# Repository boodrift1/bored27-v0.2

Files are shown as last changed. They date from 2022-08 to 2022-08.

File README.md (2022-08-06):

# bored27-v0.2
*WARNING: This PCB has not been tested and there is currently no firmware available for it.

bored27 - 27 key PCB inspired by flurples' cardboard keyboard: https://www.youtube.com/watch?v=sVInBOLSqoM <br />
designed for use with plate provided in original video description

changes from v0.1: <br />
moved diodes to front (inspired by mode designs' pcbs) <br />
changed from atmega32u4 to atmega32u2 (less components, simpler, cheaper)

designed w/ kicad

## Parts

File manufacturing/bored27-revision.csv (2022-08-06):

Id | Designator | Package | Quantity | Designation | Supplier and ref
1 | R3,R4 | R_0805_2012Metric_Pad1.20x1.40mm_HandSolder | 2 | 22
2 | C4,C5 | C_0805_2012Metric_Pad1.18x1.45mm_HandSolder | 2 | 0.1uF
3 | D13,D15,D23,D1,D9,D26,D5,D24,D2,D16,D8,D25,D21,D22,D18,D12,D10,D27,D7,D20,D6,D14,D19,D17,D11,D3,D4 | D_SOD-123 | 27 | D
4 | R6,R5 | R_0805_2012Metric_Pad1.20x1.40mm_HandSolder | 2 | 10k
5 | FB1 | L_0805_2012Metric_Pad1.15x1.40mm_HandSolder | 1 | 60@100MHz
6 | C6 | C_0805_2012Metric_Pad1.18x1.45mm_HandSolder | 1 | 10uF
7 | U2 | SOT143B | 1 | PRTR5V0U2X
8 | C1,C2 | C_0805_2012Metric_Pad1.18x1.45mm_HandSolder | 2 | 22pF
9 | SW1 | SW_SPST_SKQG_WithStem | 1 | SW_Push
10 | F1 | Fuse_1206_3216Metric_Pad1.42x1.75mm_HandSolder | 1 | 500mA
11 | X1 | Crystal_SMD_3225-4Pin_3.2x2.5mm_HandSoldering | 1 | 16MHz
12 | R1,R2 | R_0805_2012Metric_Pad1.20x1.40mm_HandSolder | 2 | 5.1k
13 | C3 | C_0805_2012Metric_Pad1.18x1.45mm_HandSolder | 1 | 1uF
14 | J1 | USB_C_Receptacle_HRO_TYPE-C-31-M-12 | 1 | USB_C_Receptacle_USB2.0
15 | U1 | TQFP-32_7x7mm_P0.8mm | 1 | ATmega32U2-A
16 | K5 | SW_MX_HS_1u | 1 | T
17 | K14 | SW_MX_HS_1u | 1 | F
18 | K11 | SW_MX_HS_1u | 1 | A
19 | K25 | SW_MX_HS_1u | 1 | N
20 | K16 | SW_MX_HS_1u | 1 | H
21 | K10 | SW_MX_HS_1u | 1 | P
22 | K8 | SW_MX_HS_1u | 1 | I
23 | K9 | SW_MX_HS_1u | 1 | O
24 | J2 | Reset_Pretty-Mask | 1 | AVR-ISP-6
25 | K13 | SW_MX_HS_1u | 1 | D
26 | K24 | SW_MX_HS_1u | 1 | B
27 | K7 | SW_MX_HS_1u | 1 | U
28 | K27 | SW_MX_HS_1u | 1 | SPACE
29 | K19 | SW_MX_HS_1u | 1 | L
30 | K22 | SW_MX_HS_1u | 1 | C
31 | K23 | SW_MX_HS_1u | 1 | V
32 | K21 | SW_MX_HS_1u | 1 | X
33 | K4 | SW_MX_HS_1u | 1 | R
34 | K18 | SW_MX_HS_1u | 1 | K
35 | K3 | SW_MX_HS_1u | 1 | E
36 | K15 | SW_MX_HS_1u | 1 | G
37 | K2 | SW_MX_HS_1u | 1 | W
38 | K20 | SW_MX_HS_1u | 1 | Z
39 | K17 | SW_MX_HS_1u | 1 | J
40 | K26 | SW_MX_HS_1u | 1 | M
41 | K1 | SW_MX_HS_1u | 1 | Q
42 | K12 | SW_MX_HS_1u | 1 | S
43 | K6 | SW_MX_HS_1u | 1 | Y

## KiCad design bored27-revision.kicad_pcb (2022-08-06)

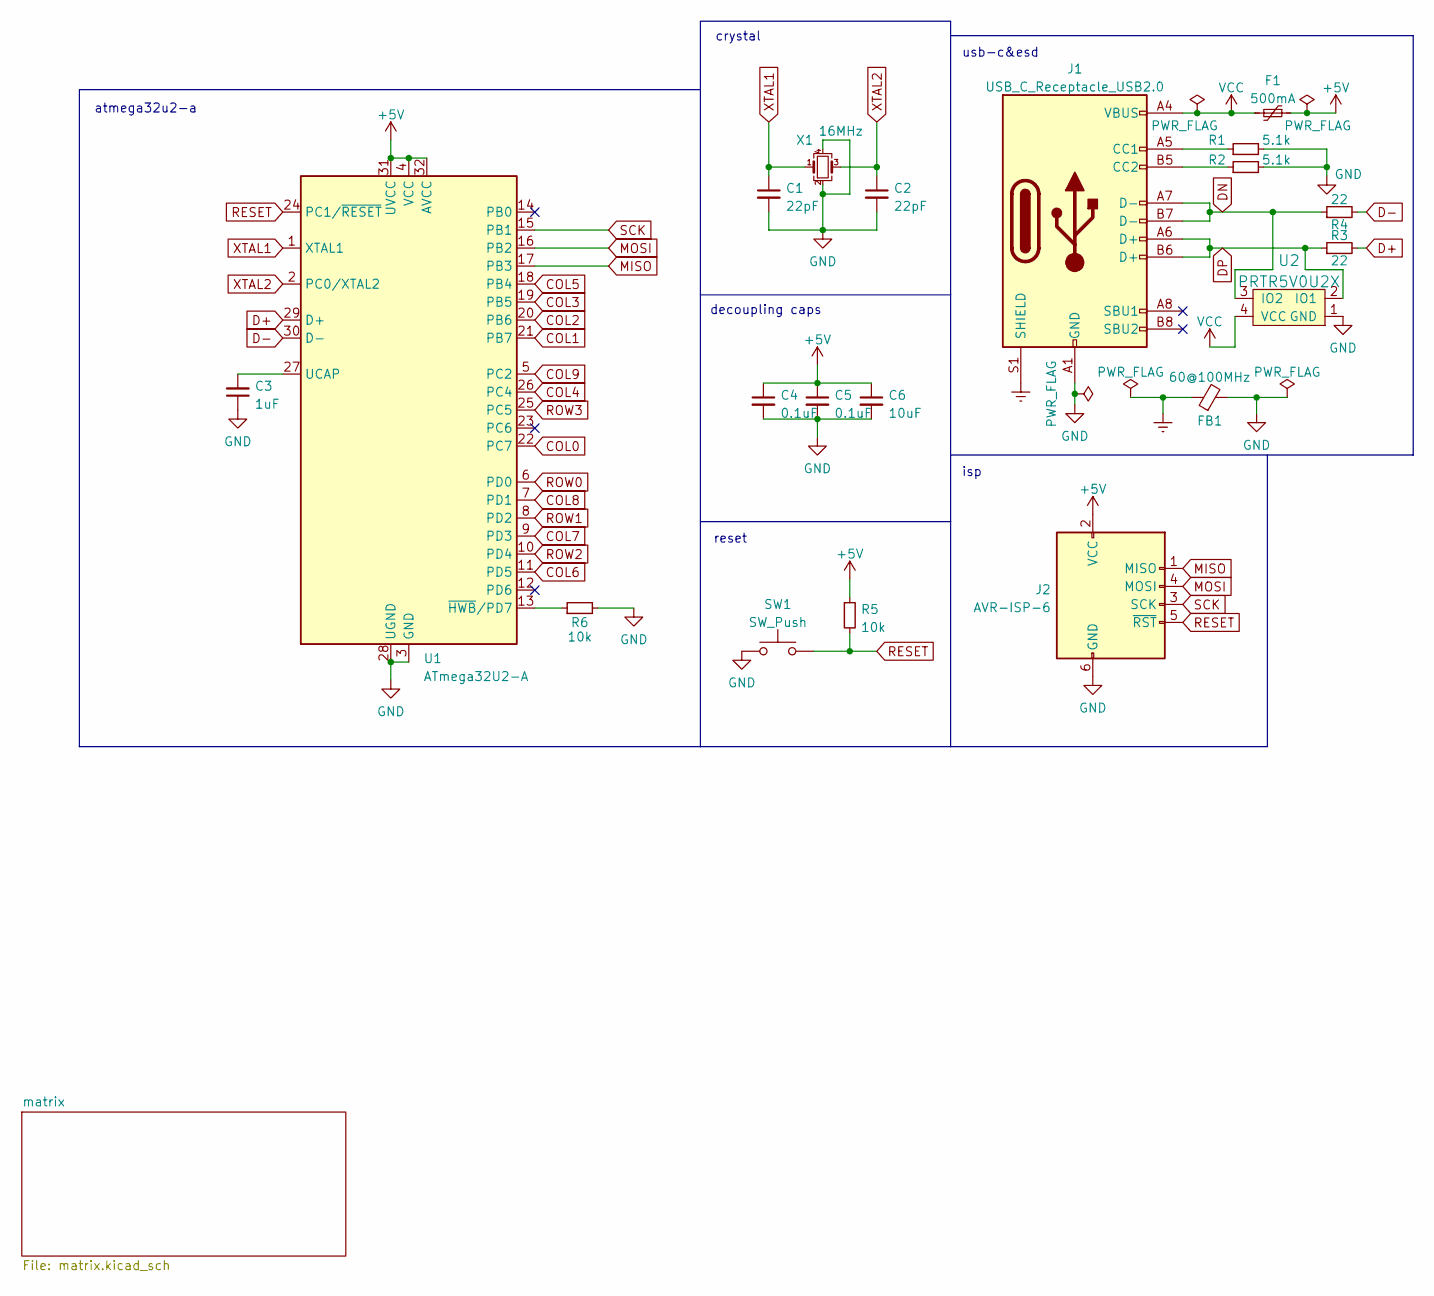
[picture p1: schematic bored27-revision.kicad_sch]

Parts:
C1, C2: 22pF; C_0805_2012Metric_Pad1.18x1.45mm_HandSolder
C3: 1uF; C_0805_2012Metric_Pad1.18x1.45mm_HandSolder
C4, C5: 0.1uF; C_0805_2012Metric_Pad1.18x1.45mm_HandSolder
C6: 10uF; C_0805_2012Metric_Pad1.18x1.45mm_HandSolder
F1: 500mA; Fuse_1206_3216Metric_Pad1.42x1.75mm_HandSolder
FB1: 60@100MHz; L_0805_2012Metric_Pad1.15x1.40mm_HandSolder
J1: USB_C_Receptacle_USB2.0; USB_C_Receptacle_HRO_TYPE-C-31-M-12
J2: AVR-ISP-6; Reset_Pretty-Mask
R1, R2: 5.1k; R_0805_2012Metric_Pad1.20x1.40mm_HandSolder
R3, R4: 22; R_0805_2012Metric_Pad1.20x1.40mm_HandSolder
R5, R6: 10k; R_0805_2012Metric_Pad1.20x1.40mm_HandSolder
SW1: SW_Push; SW_SPST_SKQG_WithStem
U1: ATmega32U2-A; TQFP-32_7x7mm_P0.8mm
U2: PRTR5V0U2X; SOT143B
X1: 16MHz; Crystal_SMD_3225-4Pin_3.2x2.5mm_HandSoldering

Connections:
+5V: C4.1, C5.1, C6.1, F1.1, J2.2 (VCC), R5.1, U1.4 (VCC), U1.31 (UVCC), U1.32 (AVCC)
COL0: U1.22 (PC7); also elsewhere on the board
COL1: U1.21 (PB7); also elsewhere on the board
COL2: U1.20 (PB6); also elsewhere on the board
COL3: U1.19 (PB5); also elsewhere on the board
COL4: U1.26 (PC4); also elsewhere on the board
COL5: U1.18 (PB4); also elsewhere on the board
COL6: U1.11 (PD5); also elsewhere on the board
COL7: U1.9 (PD3); also elsewhere on the board
COL8: U1.7 (PD1); also elsewhere on the board
COL9: U1.5 (PC2); also elsewhere on the board
D+: R3.2, U1.29 (D+)
D-: R4.2, U1.30 (D-)
DN: J1.A7 (D-), J1.B7 (D-), R4.1, U2.3 (IO2)
DP: J1.A6 (D+), J1.B6 (D+), R3.1, U2.2 (IO1)
Earth: FB1.1, J1.S1 (SHIELD)
GND: C1.2, C2.2, C3.1, C4.2, C5.2, C6.2, FB1.2, J1.A1 (GND), J1.A12 (GND), J1.B1 (GND), J1.B12 (GND), J2.6 (GND), R1.2, R2.2, R6.2, SW1.1, U1.3 (GND), U1.28 (UGND), U2.1 (GND), X1.2, X1.4
MISO: J2.1 (MISO), U1.17 (PB3)
MOSI: J2.4 (MOSI), U1.16 (PB2)
unnamed: C3.2, U1.27 (UCAP)
unnamed: J1.A5 (CC1), R1.1
unnamed: J1.B5 (CC2), R2.1
unnamed: R6.1, U1.13 (~HWB/PD7)
RESET: J2.5 (~RST), R5.2, SW1.2, U1.24 (PC1/~RESET)
ROW0: U1.6 (PD0); also elsewhere on the board
ROW1: U1.8 (PD2); also elsewhere on the board
ROW2: U1.10 (PD4); also elsewhere on the board
ROW3: U1.25 (PC5); also elsewhere on the board
SCK: J2.3 (SCK), U1.15 (PB1)
VCC: F1.2, J1.A4 (VBUS), J1.A9 (VBUS), J1.B4 (VBUS), J1.B9 (VBUS), U2.4 (VCC)
XTAL1: C1.1, U1.1 (XTAL1), X1.1
XTAL2: C2.1, U1.2 (PC0/XTAL2), X1.3

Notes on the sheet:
crystal
usb-c&esd
decoupling caps
atmega32u2-a
isp
reset

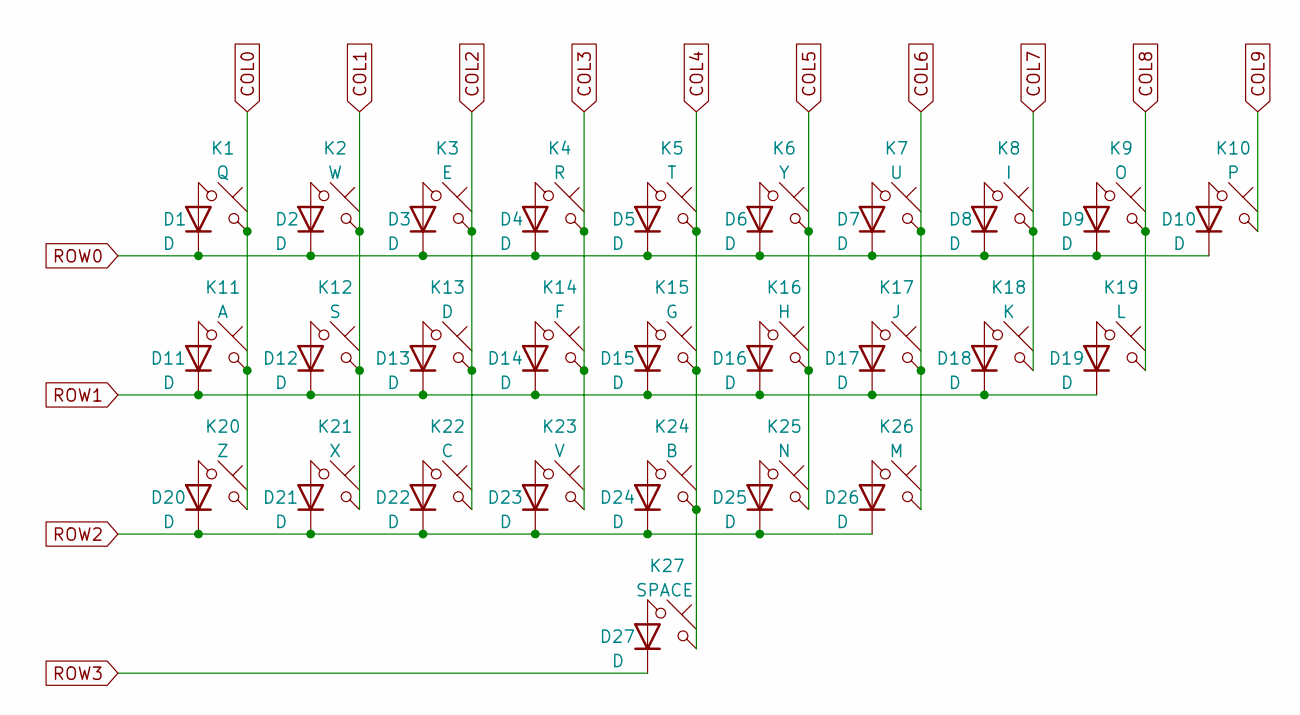
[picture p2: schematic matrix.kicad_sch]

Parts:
D1, D2, D3, D4, D5, D6, D7, D8, D9, D10, D11, D12, D13, D14, D15, D16, D17, D18, D19, D20, D21, D22, D23, D24, D25, D26, D27: D; D_SOD-123
K1: Q; SW_MX_HS_1u
K2: W; SW_MX_HS_1u
K3: E; SW_MX_HS_1u
K4: R; SW_MX_HS_1u
K5: T; SW_MX_HS_1u
K6: Y; SW_MX_HS_1u
K7: U; SW_MX_HS_1u
K8: I; SW_MX_HS_1u
K9: O; SW_MX_HS_1u
K10: P; SW_MX_HS_1u
K11: A; SW_MX_HS_1u
K12: S; SW_MX_HS_1u
K13: D; SW_MX_HS_1u
K14: F; SW_MX_HS_1u
K15: G; SW_MX_HS_1u
K16: H; SW_MX_HS_1u
K17: J; SW_MX_HS_1u
K18: K; SW_MX_HS_1u
K19: L; SW_MX_HS_1u
K20: Z; SW_MX_HS_1u
K21: X; SW_MX_HS_1u
K22: C; SW_MX_HS_1u
K23: V; SW_MX_HS_1u
K24: B; SW_MX_HS_1u
K25: N; SW_MX_HS_1u
K26: M; SW_MX_HS_1u
K27: SPACE; SW_MX_HS_1u

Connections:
COL0: K1.2, K11.2, K20.2; also elsewhere on the board
COL1: K2.2, K12.2, K21.2; also elsewhere on the board
COL2: K3.2, K13.2, K22.2; also elsewhere on the board
COL3: K4.2, K14.2, K23.2; also elsewhere on the board
COL4: K5.2, K15.2, K24.2, K27.2; also elsewhere on the board
COL5: K6.2, K16.2, K25.2; also elsewhere on the board
COL6: K7.2, K17.2, K26.2; also elsewhere on the board
COL7: K8.2, K18.2; also elsewhere on the board
COL8: K9.2, K19.2; also elsewhere on the board
COL9: K10.2; also elsewhere on the board
unnamed: D1.2 (A), K1.1
unnamed: D2.2 (A), K2.1
unnamed: D3.2 (A), K3.1
unnamed: D4.2 (A), K4.1
unnamed: D5.2 (A), K5.1
unnamed: D6.2 (A), K6.1
unnamed: D7.2 (A), K7.1
unnamed: D8.2 (A), K8.1
unnamed: D9.2 (A), K9.1
unnamed: D10.2 (A), K10.1
unnamed: D11.2 (A), K11.1
unnamed: D12.2 (A), K12.1
unnamed: D13.2 (A), K13.1
unnamed: D14.2 (A), K14.1
unnamed: D15.2 (A), K15.1
unnamed: D16.2 (A), K16.1
unnamed: D17.2 (A), K17.1
unnamed: D18.2 (A), K18.1
unnamed: D19.2 (A), K19.1
unnamed: D20.2 (A), K20.1
unnamed: D21.2 (A), K21.1
unnamed: D22.2 (A), K22.1
unnamed: D23.2 (A), K23.1
unnamed: D24.2 (A), K24.1
unnamed: D25.2 (A), K25.1
unnamed: D26.2 (A), K26.1
unnamed: D27.2 (A), K27.1
ROW0: D1.1 (K), D2.1 (K), D3.1 (K), D4.1 (K), D5.1 (K), D6.1 (K), D7.1 (K), D8.1 (K), D9.1 (K), D10.1 (K); also elsewhere on the board
ROW1: D11.1 (K), D12.1 (K), D13.1 (K), D14.1 (K), D15.1 (K), D16.1 (K), D17.1 (K), D18.1 (K), D19.1 (K); also elsewhere on the board
ROW2: D20.1 (K), D21.1 (K), D22.1 (K), D23.1 (K), D24.1 (K), D25.1 (K), D26.1 (K); also elsewhere on the board
ROW3: D27.1 (K); also elsewhere on the board

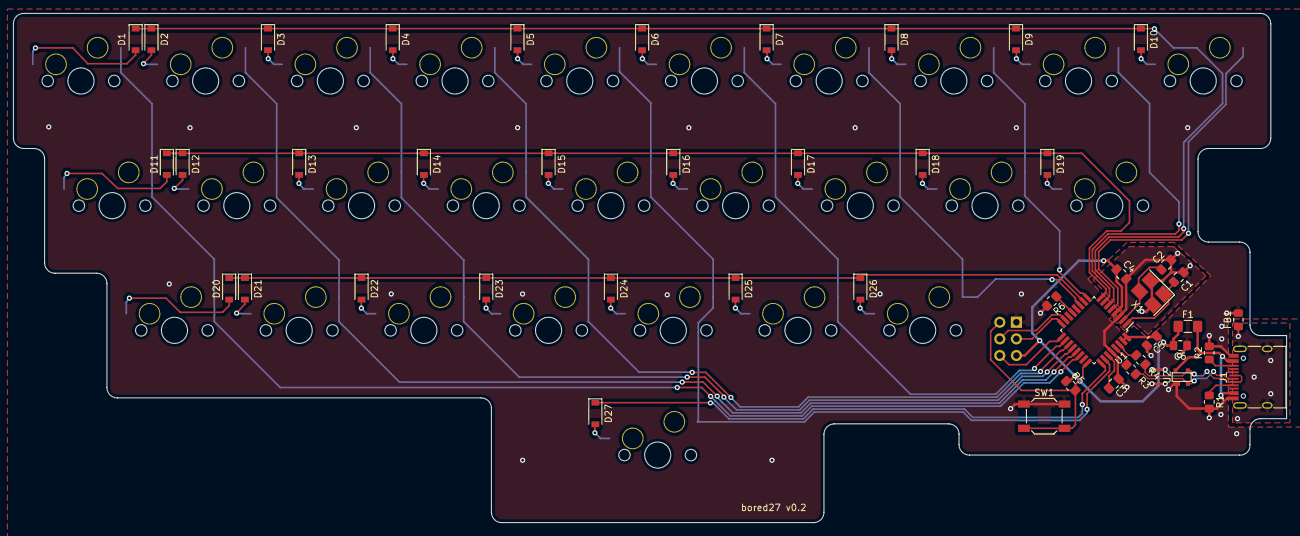
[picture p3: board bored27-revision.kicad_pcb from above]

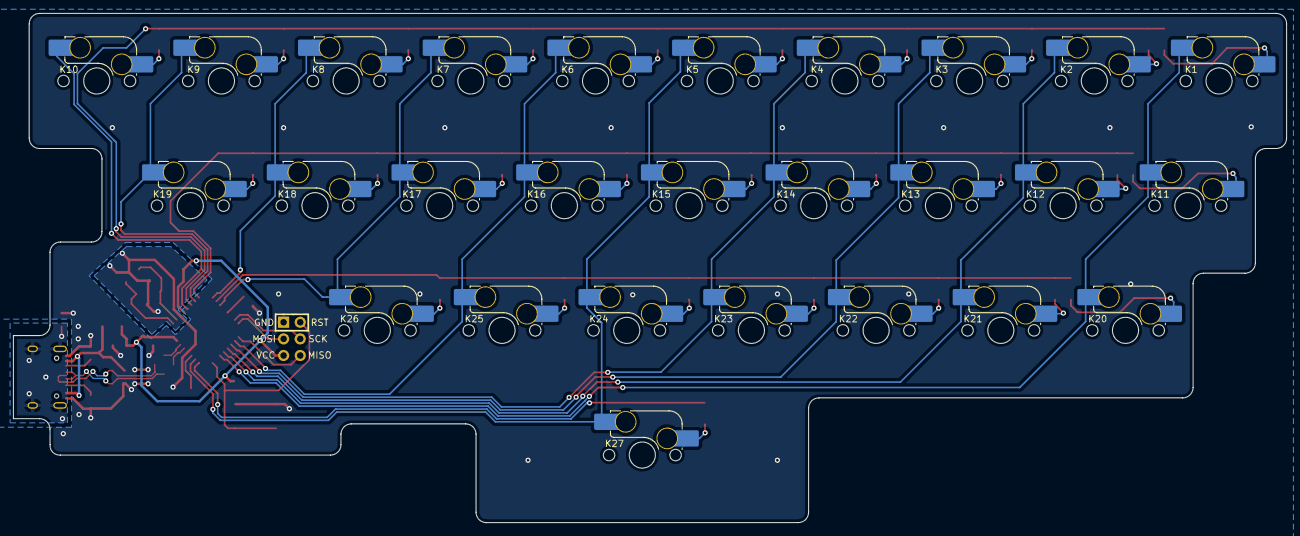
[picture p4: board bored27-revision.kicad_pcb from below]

Board: 2 copper layers, 194.5 x 77.8 mm, 74 parts (28 on the bottom side), 59 nets.

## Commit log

2022-08-04 initializing project
    [bored27-revision.kicad_pcb, bored27-revision.kicad_sch]
2022-08-04 i screwed up with the files AAAAA
    [bored27-revision.kicad_pcb, bored27-revision.kicad_sch]
2022-08-05 mostly finished schematic
    [bored27-revision.kicad_sch, matrix.kicad_sch]
2022-08-05 beginning pcb
    [bored27-revision.kicad_pcb]
2022-08-05 placement of pcb components
    [bored27-revision.kicad_pcb]
2022-08-06 finished pcb
    [bored27-revision.kicad_pcb, bored27-revision.kicad_sch]
2022-08-06 generated gerber files
    [bored27-revision-B_Cu.gbr, bored27-revision-B_Mask.gbr, bored27-revision-B_Silkscreen.gbr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]
2022-08-06 generated csv file
    [bored27-revision-B_Cu.gbr, bored27-revision-B_Mask.gbr, bored27-revision-B_Silkscreen.gbr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]
